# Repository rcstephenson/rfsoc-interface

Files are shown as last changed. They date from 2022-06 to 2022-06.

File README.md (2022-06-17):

# RFSoC Breakout Board

This repo is for KiCAD6 projects replacing the FMC-XM500 daughter card with a smaller version using low frequency baluns and external differential clocking breakout board. 

## RFSoC_Frontend:
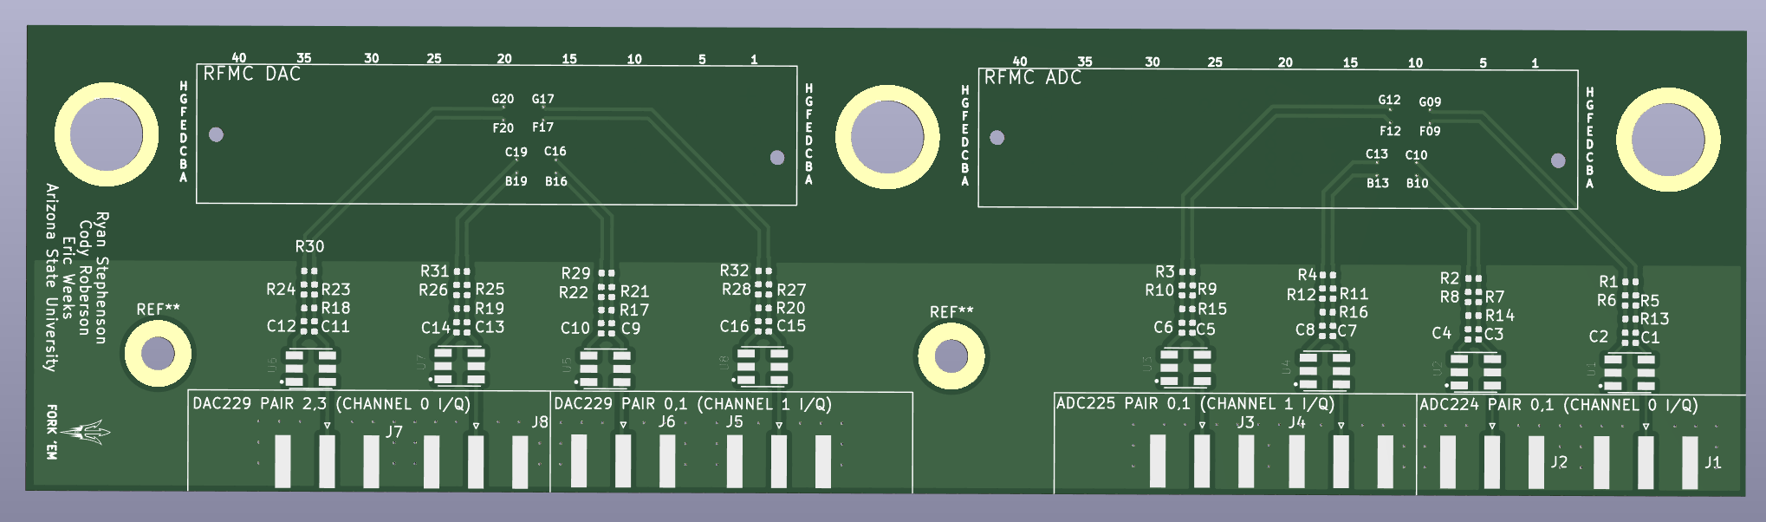
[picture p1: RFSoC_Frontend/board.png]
RFSoC front end breakout board


## RFSoC_directclocking:
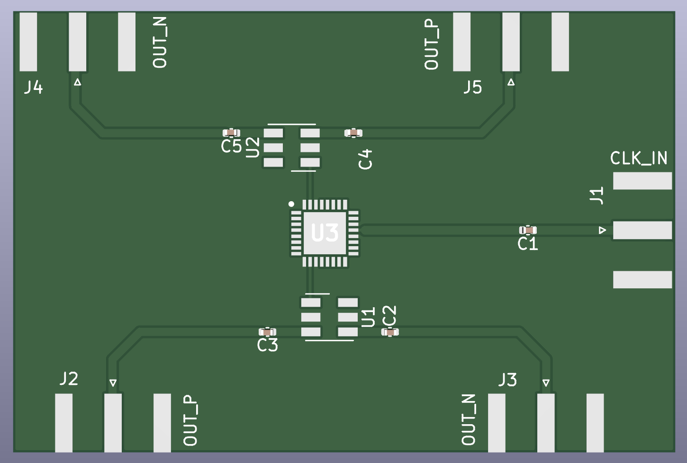
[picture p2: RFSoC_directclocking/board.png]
differential brekaout and power splitter for DAC/ADC


---
signifigent contributions have been made by Eric Weeks and Cody Roberson at ASU to make this board operational.

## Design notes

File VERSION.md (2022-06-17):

v0.1
- includes first three 2-channel boards fabricated, mounting holes were misaligned and did not physically fit on RFSoC. 
- Transmission lines are 50Ohm single ended grounded CPWs on input and 100Ohm differential microstrip lines before/after balun respectively. See XM500.pdf for original design info.

v1.0
- first fabricated version of board which works on RFSoC, same rf-lines, fixed position of mountion holes. 
- measuered I/Q data in loopback. 

added differential clocking board

V1.1
- added correct schematic to fix shorted grounds (Eric and Cody)
- updated PCB traces

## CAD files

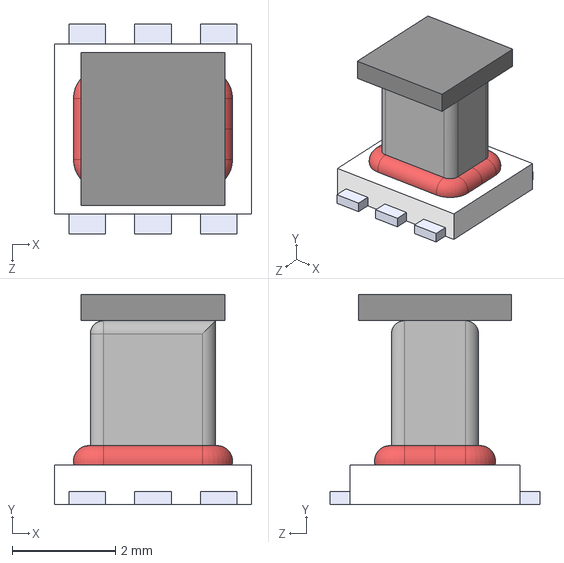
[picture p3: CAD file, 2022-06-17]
RFSoC_directclocking/TCM2-33WX_/TCM2-33WX_.step
3.81 x 4.06 x 4.06 mm

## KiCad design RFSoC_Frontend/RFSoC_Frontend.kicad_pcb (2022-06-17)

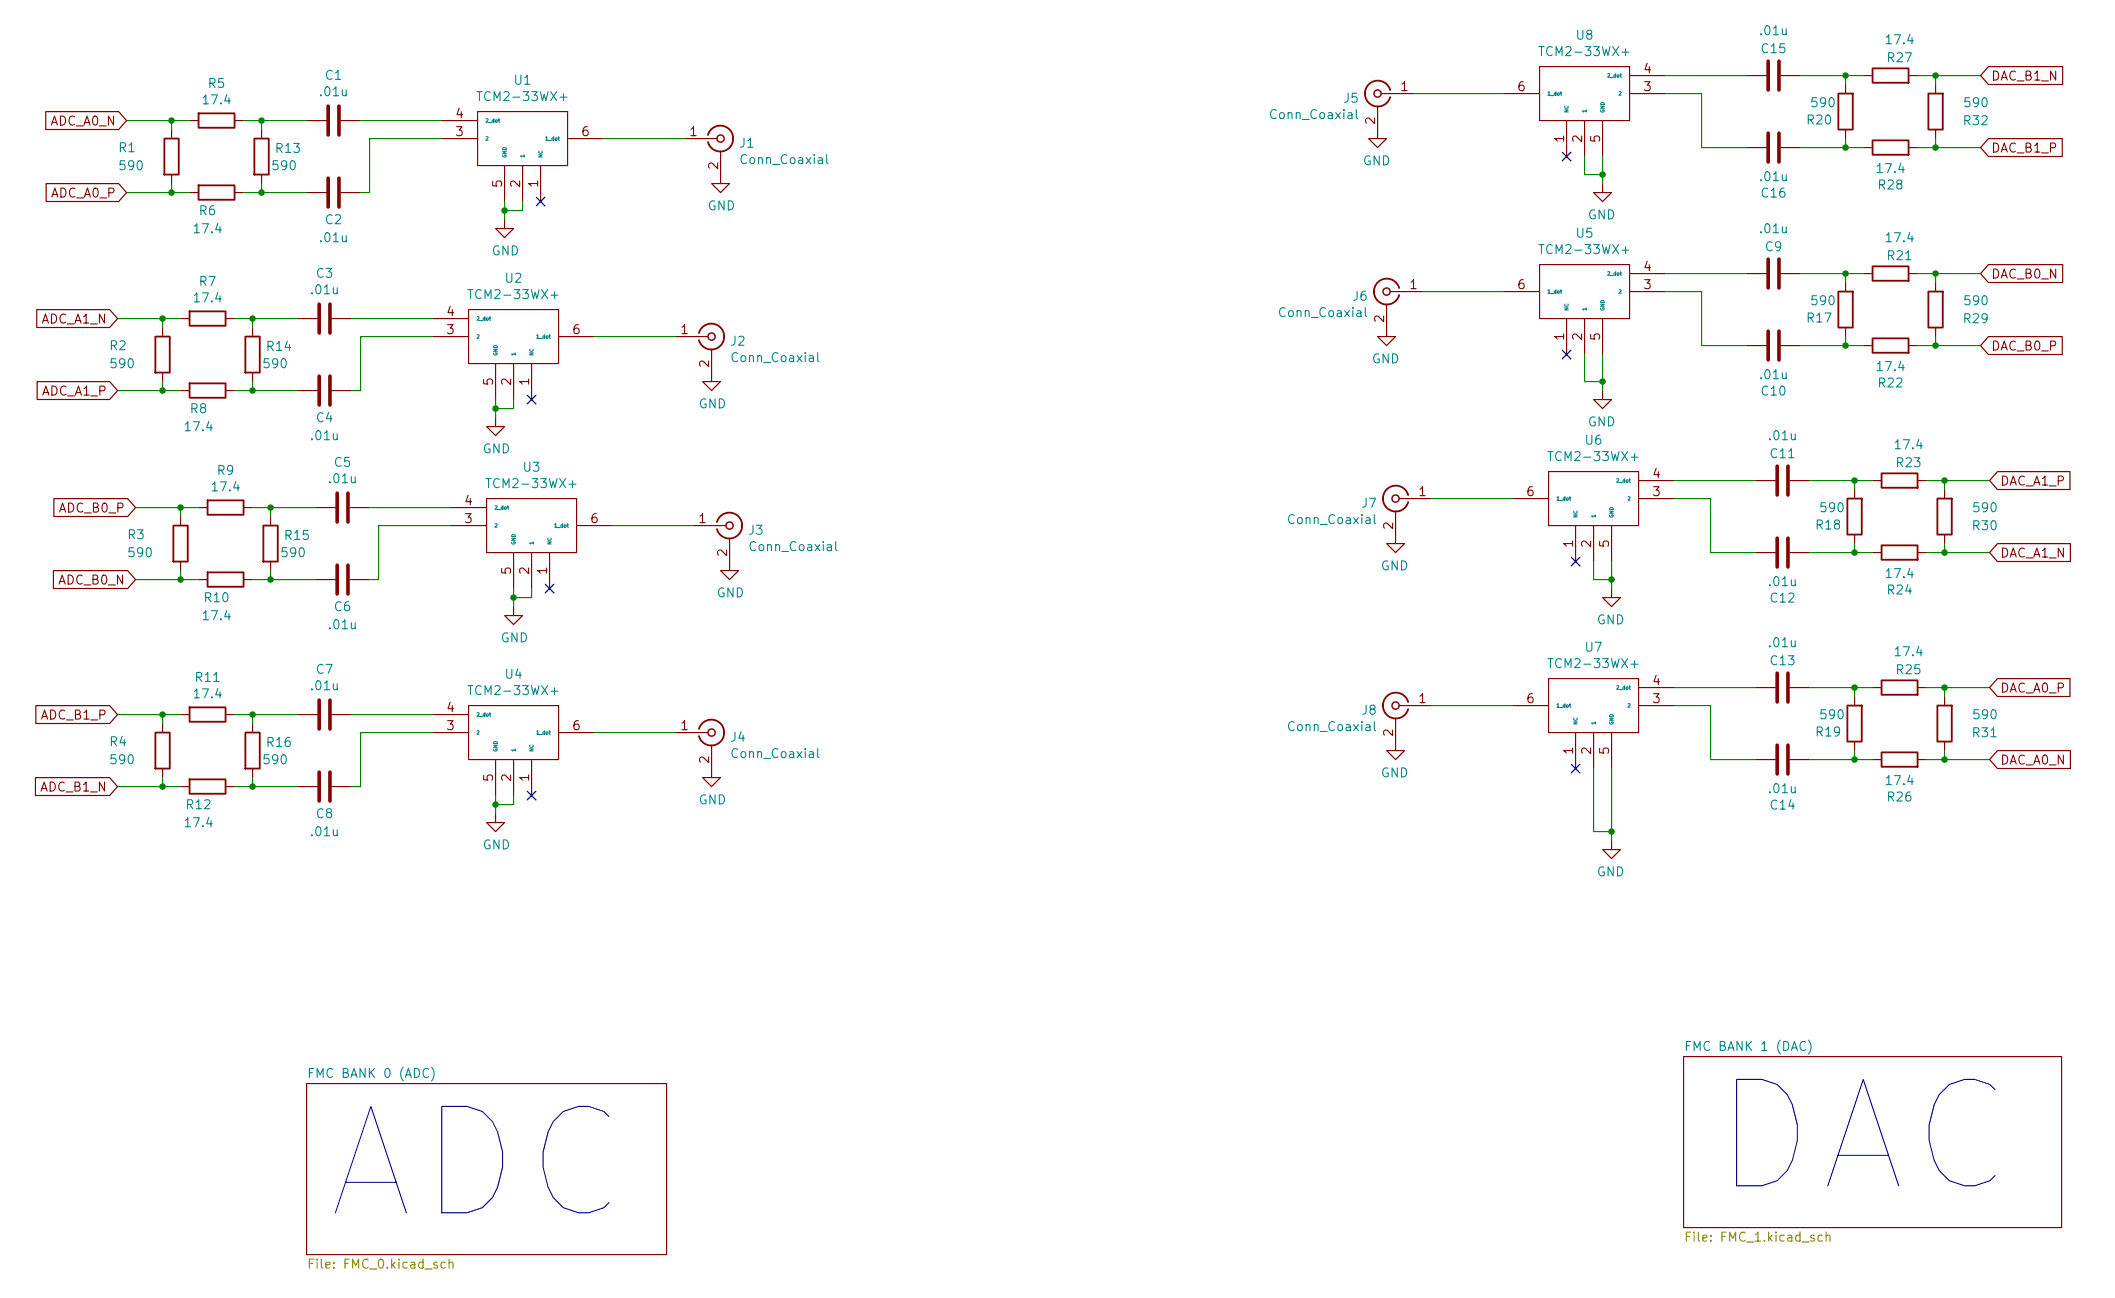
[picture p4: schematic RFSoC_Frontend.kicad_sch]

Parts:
C1, C2, C3, C4, C5, C6, C7, C8, C9, C10, C11, C12, C13, C14, C15, C16: .01u; C_0402_1005Metric
J1, J2, J3, J4, J5, J6, J7, J8: Conn_Coaxial; SMA_Amphenol_132289_EdgeMount
R1, R2, R3, R4, R13, R14, R15, R16, R17, R18, R19, R20, R29, R30, R31, R32: 590; R_0402_1005Metric
R5, R6, R7, R8, R9, R10, R11, R12, R21, R22, R23, R24, R25, R26, R27, R28: 17.4; R_0402_1005Metric
U1, U2, U3, U4, U5, U6, U7, U8: TCM2-33WX+; XFMR_TCM2-33WX+

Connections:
ADC_A0_N: R1.1, R5.2; also elsewhere on the board
ADC_A0_P: R1.2, R6.2; also elsewhere on the board
ADC_A1_N: R2.1, R7.2; also elsewhere on the board
ADC_A1_P: R2.2, R8.2; also elsewhere on the board
ADC_B0_N: R3.2, R10.2; also elsewhere on the board
ADC_B0_P: R3.1, R9.2; also elsewhere on the board
ADC_B1_N: R4.2, R12.2; also elsewhere on the board
ADC_B1_P: R4.1, R11.2; also elsewhere on the board
DAC_A0_N: R26.2, R31.1; also elsewhere on the board
DAC_A0_P: R25.2, R31.2; also elsewhere on the board
DAC_A1_N: R24.2, R30.1; also elsewhere on the board
DAC_A1_P: R23.2, R30.2; also elsewhere on the board
DAC_B0_N: R21.2, R29.2; also elsewhere on the board
DAC_B0_P: R22.2, R29.1; also elsewhere on the board
DAC_B1_N: R27.2, R32.2; also elsewhere on the board
DAC_B1_P: R28.2, R32.1; also elsewhere on the board
GND: J1.2 (Ext), J2.2 (Ext), J3.2 (Ext), J4.2 (Ext), J5.2 (Ext), J6.2 (Ext), J7.2 (Ext), J8.2 (Ext), U1.2 (1), U1.5 (GND), U2.2 (1), U2.5 (GND), U3.2 (1), U3.5 (GND), U4.2 (1), U4.5 (GND), U5.2 (1), U5.5 (GND), U6.2 (1), U6.5 (GND), U7.2 (1), U7.5 (GND), U8.2 (1), U8.5 (GND); also elsewhere on the board
unnamed: C1.1, U1.4 (2_dot)
unnamed: C1.2, R5.1, R13.1
unnamed: C2.1, U1.3 (2)
unnamed: C2.2, R6.1, R13.2
unnamed: C3.1, U2.4 (2_dot)
unnamed: C3.2, R7.1, R14.1
unnamed: C4.1, U2.3 (2)
unnamed: C4.2, R8.1, R14.2
unnamed: C5.1, U3.4 (2_dot)
unnamed: C5.2, R9.1, R15.1
unnamed: C6.1, U3.3 (2)
unnamed: C6.2, R10.1, R15.2
unnamed: C7.1, U4.4 (2_dot)
unnamed: C7.2, R11.1, R16.1
unnamed: C8.1, U4.3 (2)
unnamed: C8.2, R12.1, R16.2
unnamed: C9.1, U5.4 (2_dot)
unnamed: C9.2, R17.2, R21.1
unnamed: C10.1, U5.3 (2)
unnamed: C10.2, R17.1, R22.1
unnamed: C11.1, U6.4 (2_dot)
unnamed: C11.2, R18.2, R23.1
unnamed: C12.1, U6.3 (2)
unnamed: C12.2, R18.1, R24.1
unnamed: C13.1, U7.4 (2_dot)
unnamed: C13.2, R19.2, R25.1
unnamed: C14.1, U7.3 (2)
unnamed: C14.2, R19.1, R26.1
unnamed: C15.1, U8.4 (2_dot)
unnamed: C15.2, R20.2, R27.1
unnamed: C16.1, U8.3 (2)
unnamed: C16.2, R20.1, R28.1
unnamed: J1.1 (In), U1.6 (1_dot)
unnamed: J2.1 (In), U2.6 (1_dot)
unnamed: J3.1 (In), U3.6 (1_dot)
unnamed: J4.1 (In), U4.6 (1_dot)
unnamed: J5.1 (In), U8.6 (1_dot)
unnamed: J6.1 (In), U5.6 (1_dot)
unnamed: J7.1 (In), U6.6 (1_dot)
unnamed: J8.1 (In), U7.6 (1_dot)

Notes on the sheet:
ADC
DAC

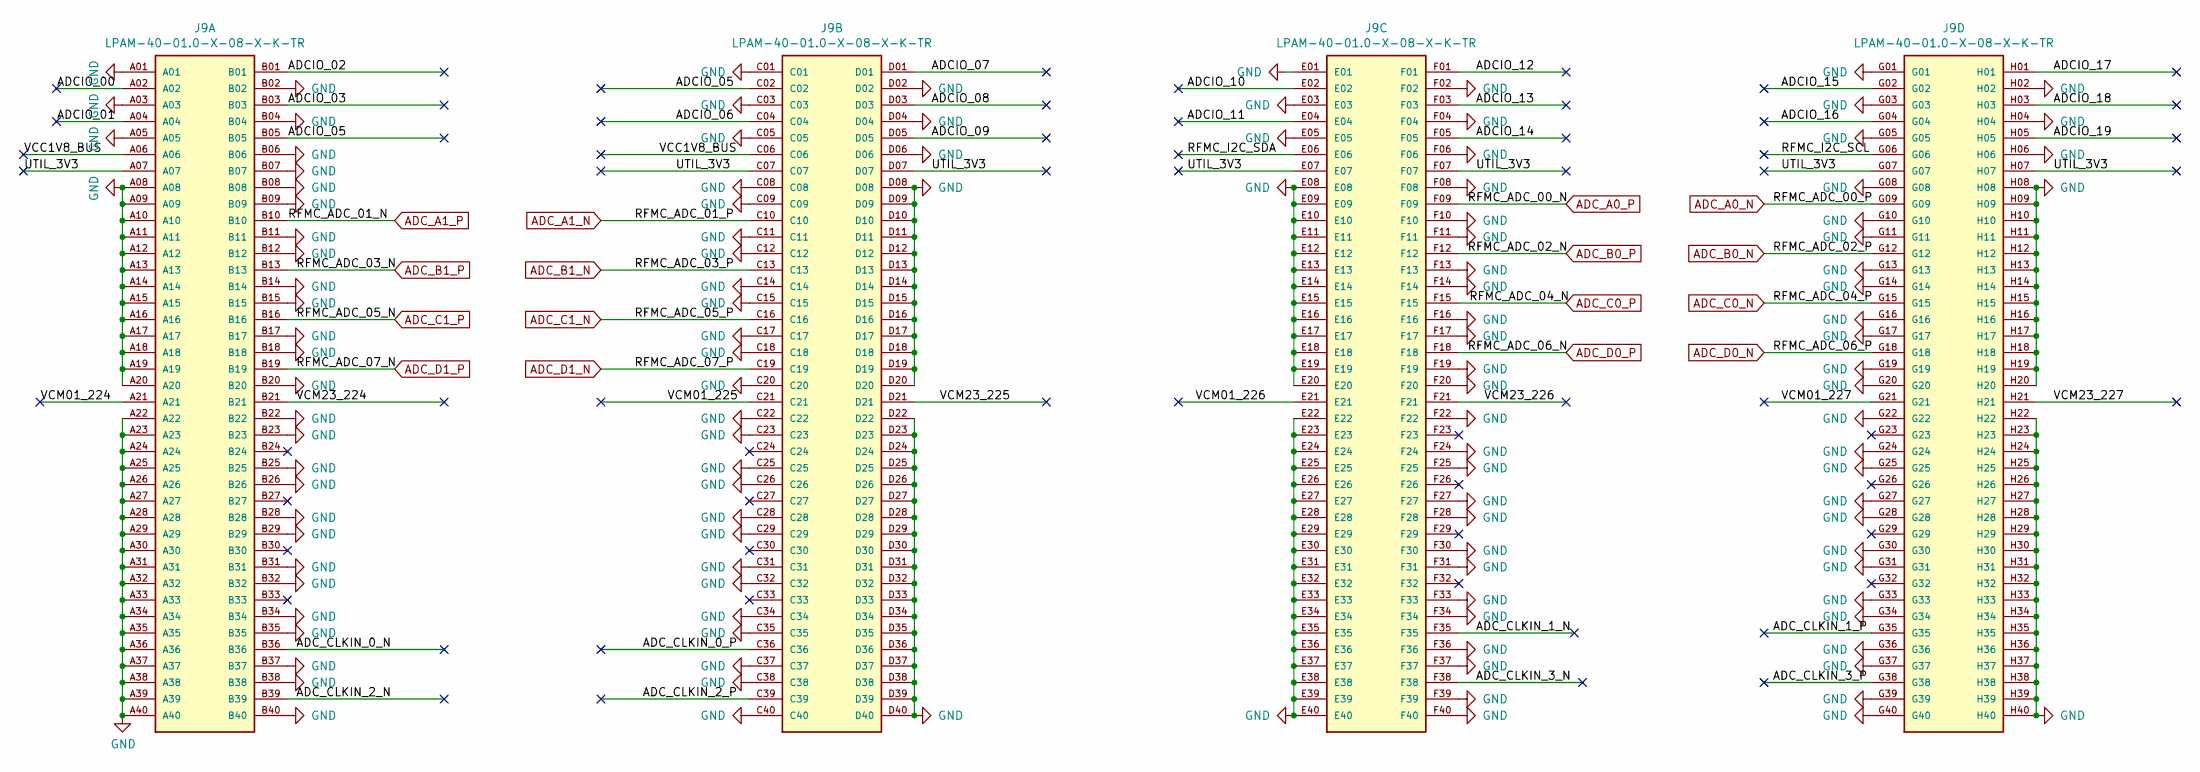
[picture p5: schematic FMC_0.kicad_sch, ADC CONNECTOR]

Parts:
J9: LPAM-40-01.0-X-08-X-K-TR; SAMTEC_LPAM-40-01.0-X-08-X-K-TR; PARTREV E

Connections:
/FMC BANK 0 (ADC)/ADCIO_00: J9.A02
/FMC BANK 0 (ADC)/ADCIO_01: J9.A04
/FMC BANK 0 (ADC)/ADCIO_02: J9.B01
/FMC BANK 0 (ADC)/ADCIO_03: J9.B03
/FMC BANK 0 (ADC)/ADCIO_05: J9.B05, J9.C02
/FMC BANK 0 (ADC)/ADCIO_06: J9.C04
/FMC BANK 0 (ADC)/ADCIO_07: J9.D01
/FMC BANK 0 (ADC)/ADCIO_08: J9.D03
/FMC BANK 0 (ADC)/ADCIO_09: J9.D05
/FMC BANK 0 (ADC)/ADCIO_10: J9.E02
/FMC BANK 0 (ADC)/ADCIO_11: J9.E04
/FMC BANK 0 (ADC)/ADCIO_12: J9.F01
/FMC BANK 0 (ADC)/ADCIO_13: J9.F03
/FMC BANK 0 (ADC)/ADCIO_14: J9.F05
/FMC BANK 0 (ADC)/ADCIO_15: J9.G02
/FMC BANK 0 (ADC)/ADCIO_16: J9.G04
/FMC BANK 0 (ADC)/ADCIO_17: J9.H01
/FMC BANK 0 (ADC)/ADCIO_18: J9.H03
/FMC BANK 0 (ADC)/ADCIO_19: J9.H05
/FMC BANK 0 (ADC)/ADC_CLKIN_0_N: J9.B36
/FMC BANK 0 (ADC)/ADC_CLKIN_0_P: J9.C36
/FMC BANK 0 (ADC)/ADC_CLKIN_1_N: J9.F35
/FMC BANK 0 (ADC)/ADC_CLKIN_1_P: J9.G35
/FMC BANK 0 (ADC)/ADC_CLKIN_2_N: J9.B39
/FMC BANK 0 (ADC)/ADC_CLKIN_2_P: J9.C39
/FMC BANK 0 (ADC)/ADC_CLKIN_3_N: J9.F38
/FMC BANK 0 (ADC)/ADC_CLKIN_3_P: J9.G38
/FMC BANK 0 (ADC)/RFMC_I2C_SCL: J9.G06
/FMC BANK 0 (ADC)/RFMC_I2C_SDA: J9.E06
/FMC BANK 0 (ADC)/UTIL_3V3: J9.A07, J9.C07, J9.D07, J9.E07, J9.F07, J9.G07, J9.H07
/FMC BANK 0 (ADC)/VCC1V8_BUS: J9.A06, J9.C06
/FMC BANK 0 (ADC)/VCM01_224: J9.A21
/FMC BANK 0 (ADC)/VCM01_225: J9.C21
/FMC BANK 0 (ADC)/VCM01_226: J9.E21
/FMC BANK 0 (ADC)/VCM01_227: J9.G21
/FMC BANK 0 (ADC)/VCM23_224: J9.B21
/FMC BANK 0 (ADC)/VCM23_225: J9.D21
/FMC BANK 0 (ADC)/VCM23_226: J9.F21
/FMC BANK 0 (ADC)/VCM23_227: J9.H21
ADC_A0_N: J9.G09; also elsewhere on the board
ADC_A0_P: J9.F09; also elsewhere on the board
ADC_A1_N: J9.C10; also elsewhere on the board
ADC_A1_P: J9.B10; also elsewhere on the board
ADC_B0_N: J9.G12; also elsewhere on the board
ADC_B0_P: J9.F12; also elsewhere on the board
ADC_B1_N: J9.C13; also elsewhere on the board
ADC_B1_P: J9.B13; also elsewhere on the board
ADC_C0_N: J9.G15
ADC_C0_P: J9.F15
ADC_C1_N: J9.C16
ADC_C1_P: J9.B16
ADC_D0_N: J9.G18
ADC_D0_P: J9.F18
ADC_D1_N: J9.C19
ADC_D1_P: J9.B19
GND: J9.A01, J9.A03, J9.A05, J9.A08, J9.A09, J9.A10, J9.A11, J9.A12, J9.A13, J9.A14, J9.A15, J9.A16, J9.A17, J9.A18, J9.A19, J9.A20, J9.A22, J9.A23, J9.A24, J9.A25, J9.A26, J9.A27, J9.A28, J9.A29, J9.A30, J9.A31, J9.A32, J9.A33, J9.A34, J9.A35, J9.A36, J9.A37, J9.A38, J9.A39, J9.A40, J9.B02, J9.B04, J9.B06, J9.B07, J9.B08, J9.B09, J9.B11, J9.B12, J9.B14, J9.B15, J9.B17, J9.B18, J9.B20, J9.B22, J9.B23, J9.B25, J9.B26, J9.B28, J9.B29, J9.B31, J9.B32, J9.B34, J9.B35, J9.B37, J9.B38, J9.B40, J9.C01, J9.C03, J9.C05, J9.C08, J9.C09, J9.C11, J9.C12, J9.C14, J9.C15, J9.C17, J9.C18, J9.C20, J9.C22, J9.C23, J9.C25, J9.C26, J9.C28, J9.C29, J9.C31, J9.C32, J9.C34, J9.C35, J9.C37, J9.C38, J9.C40, J9.D02, J9.D04, J9.D06, J9.D08, J9.D09, J9.D10, J9.D11, J9.D12, J9.D13, J9.D14, J9.D15, J9.D16, J9.D17, J9.D18, J9.D19, J9.D20, J9.D22, J9.D23, J9.D24, J9.D25, J9.D26, J9.D27, J9.D28, J9.D29, J9.D30, J9.D31, J9.D32, J9.D33, J9.D34, J9.D35, J9.D36, J9.D37, J9.D38, J9.D39, J9.D40, J9.E01, J9.E03, J9.E05, J9.E08, J9.E09, J9.E10, J9.E11, J9.E12, J9.E13, J9.E14, J9.E15, J9.E16, J9.E17, J9.E18, J9.E19, J9.E20, J9.E22, J9.E23, J9.E24, J9.E25, J9.E26, J9.E27, J9.E28, J9.E29, J9.E30, J9.E31, J9.E32, J9.E33, J9.E34, J9.E35, J9.E36, J9.E37, J9.E38, J9.E39, J9.E40, J9.F02, J9.F04, J9.F06, J9.F08, J9.F10, J9.F11, J9.F13, J9.F14, J9.F16, J9.F17, J9.F19, J9.F20, J9.F22, J9.F24, J9.F25, J9.F27, J9.F28, J9.F30, J9.F31, J9.F33, J9.F34, J9.F36, J9.F37, J9.F39, J9.F40, J9.G01, J9.G03, J9.G05, J9.G08, J9.G10, J9.G11, J9.G13, J9.G14, J9.G16, J9.G17, J9.G19, J9.G20, J9.G22, J9.G24, J9.G25, J9.G27, J9.G28, J9.G30, J9.G31, J9.G33, J9.G34, J9.G36, J9.G37, J9.G39, J9.G40, J9.H02, J9.H04, J9.H06, J9.H08, J9.H09, J9.H10, J9.H11, J9.H12, J9.H13, J9.H14, J9.H15, J9.H16, J9.H17, J9.H18, J9.H19, J9.H20, J9.H22, J9.H23, J9.H24, J9.H25, J9.H26, J9.H27, J9.H28, J9.H29, J9.H30, J9.H31, J9.H32, J9.H33, J9.H34, J9.H35, J9.H36, J9.H37, J9.H38, J9.H39, J9.H40; also elsewhere on the board

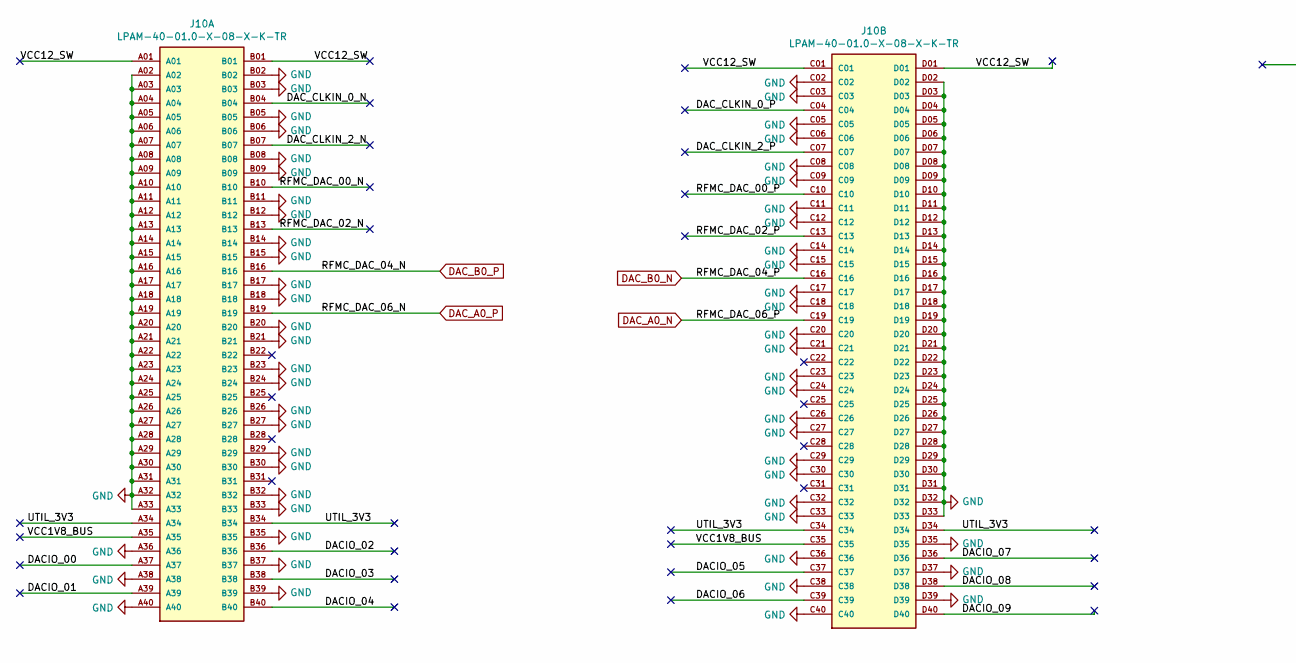
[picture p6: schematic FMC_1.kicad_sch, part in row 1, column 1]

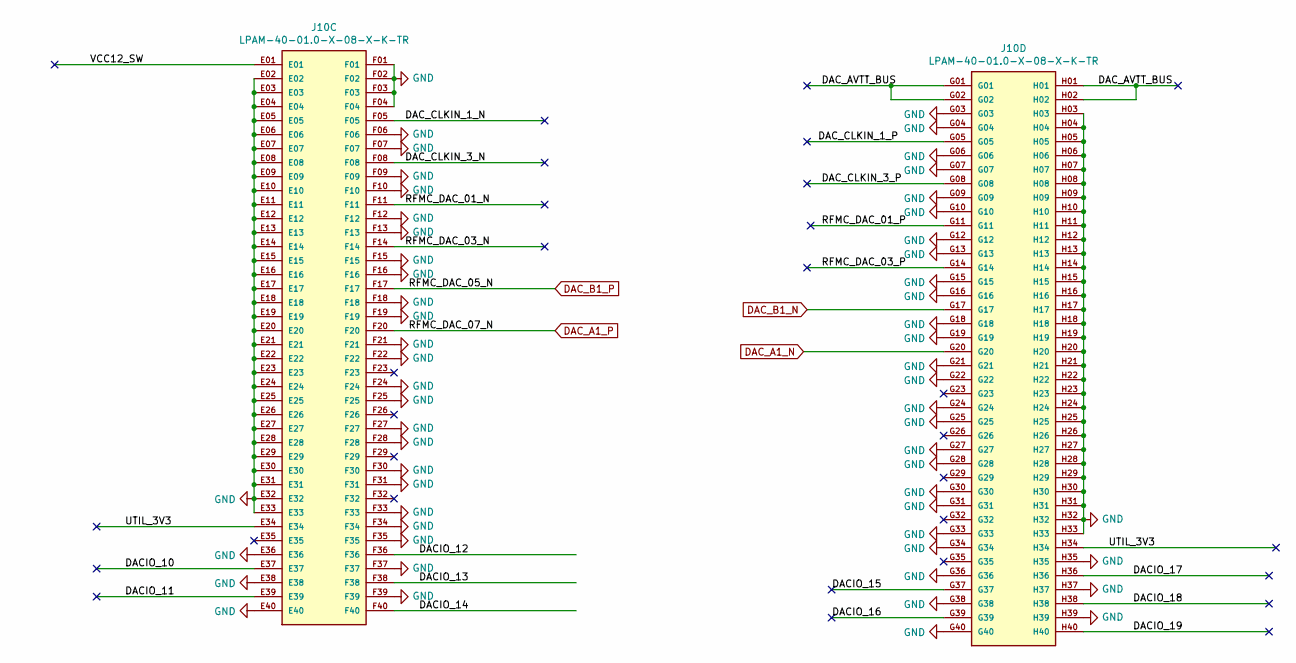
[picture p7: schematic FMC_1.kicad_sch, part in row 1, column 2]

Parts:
J10: LPAM-40-01.0-X-08-X-K-TR; SAMTEC_LPAM-40-01.0-X-08-X-K-TR; PARTREV E

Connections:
/FMC BANK 1 (DAC)/DACIO_00: J10.A37
/FMC BANK 1 (DAC)/DACIO_01: J10.A39
/FMC BANK 1 (DAC)/DACIO_02: J10.B36
/FMC BANK 1 (DAC)/DACIO_03: J10.B38
/FMC BANK 1 (DAC)/DACIO_04: J10.B40
/FMC BANK 1 (DAC)/DACIO_05: J10.C37
/FMC BANK 1 (DAC)/DACIO_06: J10.C39
/FMC BANK 1 (DAC)/DACIO_07: J10.D36
/FMC BANK 1 (DAC)/DACIO_08: J10.D38
/FMC BANK 1 (DAC)/DACIO_09: J10.D40
/FMC BANK 1 (DAC)/DACIO_10: J10.E37
/FMC BANK 1 (DAC)/DACIO_11: J10.E39
/FMC BANK 1 (DAC)/DACIO_12: J10.F36
/FMC BANK 1 (DAC)/DACIO_13: J10.F38
/FMC BANK 1 (DAC)/DACIO_14: J10.F40
/FMC BANK 1 (DAC)/DACIO_15: J10.G37
/FMC BANK 1 (DAC)/DACIO_16: J10.G39
/FMC BANK 1 (DAC)/DACIO_17: J10.H36
/FMC BANK 1 (DAC)/DACIO_18: J10.H38
/FMC BANK 1 (DAC)/DACIO_19: J10.H40
/FMC BANK 1 (DAC)/DAC_AVTT_BUS: J10.G01, J10.G02, J10.H01, J10.H02
/FMC BANK 1 (DAC)/DAC_CLKIN_0_N: J10.B04
/FMC BANK 1 (DAC)/DAC_CLKIN_0_P: J10.C04
/FMC BANK 1 (DAC)/DAC_CLKIN_1_N: J10.F05
/FMC BANK 1 (DAC)/DAC_CLKIN_1_P: J10.G05
/FMC BANK 1 (DAC)/DAC_CLKIN_2_N: J10.B07
/FMC BANK 1 (DAC)/DAC_CLKIN_2_P: J10.C07
/FMC BANK 1 (DAC)/DAC_CLKIN_3_N: J10.F08
/FMC BANK 1 (DAC)/DAC_CLKIN_3_P: J10.G08
/FMC BANK 1 (DAC)/RFMC_DAC_00_N: J10.B10
/FMC BANK 1 (DAC)/RFMC_DAC_00_P: J10.C10
/FMC BANK 1 (DAC)/RFMC_DAC_01_N: J10.F11
/FMC BANK 1 (DAC)/RFMC_DAC_01_P: J10.G11
/FMC BANK 1 (DAC)/RFMC_DAC_02_N: J10.B13
/FMC BANK 1 (DAC)/RFMC_DAC_02_P: J10.C13
/FMC BANK 1 (DAC)/RFMC_DAC_03_N: J10.F14
/FMC BANK 1 (DAC)/RFMC_DAC_03_P: J10.G14
/FMC BANK 1 (DAC)/UTIL_3V3: J10.A34, J10.B34, J10.C34, J10.D34, J10.E34, J10.H34
/FMC BANK 1 (DAC)/VCC1V8_BUS: J10.A35, J10.C35
/FMC BANK 1 (DAC)/VCC12_SW: J10.A01, J10.B01, J10.C01, J10.D01, J10.E01
DAC_A0_N: J10.C19; also elsewhere on the board
DAC_A0_P: J10.B19; also elsewhere on the board
DAC_A1_N: J10.G20; also elsewhere on the board
DAC_A1_P: J10.F20; also elsewhere on the board
DAC_B0_N: J10.C16; also elsewhere on the board
DAC_B0_P: J10.B16; also elsewhere on the board
DAC_B1_N: J10.G17; also elsewhere on the board
DAC_B1_P: J10.F17; also elsewhere on the board
GND: J10.A02, J10.A03, J10.A04, J10.A05, J10.A06, J10.A07, J10.A08, J10.A09, J10.A10, J10.A11, J10.A12, J10.A13, J10.A14, J10.A15, J10.A16, J10.A17, J10.A18, J10.A19, J10.A20, J10.A21, J10.A22, J10.A23, J10.A24, J10.A25, J10.A26, J10.A27, J10.A28, J10.A29, J10.A30, J10.A31, J10.A32, J10.A33, J10.A36, J10.A38, J10.A40, J10.B02, J10.B03, J10.B05, J10.B06, J10.B08, J10.B09, J10.B11, J10.B12, J10.B14, J10.B15, J10.B17, J10.B18, J10.B20, J10.B21, J10.B23, J10.B24, J10.B26, J10.B27, J10.B29, J10.B30, J10.B32, J10.B33, J10.B35, J10.B37, J10.B39, J10.C02, J10.C03, J10.C05, J10.C06, J10.C08, J10.C09, J10.C11, J10.C12, J10.C14, J10.C15, J10.C17, J10.C18, J10.C20, J10.C21, J10.C23, J10.C24, J10.C26, J10.C27, J10.C29, J10.C30, J10.C32, J10.C33, J10.C36, J10.C38, J10.C40, J10.D02, J10.D03, J10.D04, J10.D05, J10.D06, J10.D07, J10.D08, J10.D09, J10.D10, J10.D11, J10.D12, J10.D13, J10.D14, J10.D15, J10.D16, J10.D17, J10.D18, J10.D19, J10.D20, J10.D21, J10.D22, J10.D23, J10.D24, J10.D25, J10.D26, J10.D27, J10.D28, J10.D29, J10.D30, J10.D31, J10.D32, J10.D33, J10.D35, J10.D37, J10.D39, J10.E02, J10.E03, J10.E04, J10.E05, J10.E06, J10.E07, J10.E08, J10.E09, J10.E10, J10.E11, J10.E12, J10.E13, J10.E14, J10.E15, J10.E16, J10.E17, J10.E18, J10.E19, J10.E20, J10.E21, J10.E22, J10.E23, J10.E24, J10.E25, J10.E26, J10.E27, J10.E28, J10.E29, J10.E30, J10.E31, J10.E32, J10.E33, J10.E36, J10.E38, J10.E40, J10.F01, J10.F02, J10.F03, J10.F04, J10.F06, J10.F07, J10.F09, J10.F10, J10.F12, J10.F13, J10.F15, J10.F16, J10.F18, J10.F19, J10.F21, J10.F22, J10.F24, J10.F25, J10.F27, J10.F28, J10.F30, J10.F31, J10.F33, J10.F34, J10.F35, J10.F37, J10.F39, J10.G03, J10.G04, J10.G06, J10.G07, J10.G09, J10.G10, J10.G12, J10.G13, J10.G15, J10.G16, J10.G18, J10.G19, J10.G21, J10.G22, J10.G24, J10.G25, J10.G27, J10.G28, J10.G30, J10.G31, J10.G33, J10.G34, J10.G36, J10.G38, J10.G40, J10.H03, J10.H04, J10.H05, J10.H06, J10.H07, J10.H08, J10.H09, J10.H10, J10.H11, J10.H12, J10.H13, J10.H14, J10.H15, J10.H16, J10.H17, J10.H18, J10.H19, J10.H20, J10.H21, J10.H22, J10.H23, J10.H24, J10.H25, J10.H26, J10.H27, J10.H28, J10.H29, J10.H30, J10.H31, J10.H32, J10.H33, J10.H35, J10.H37, J10.H39; also elsewhere on the board

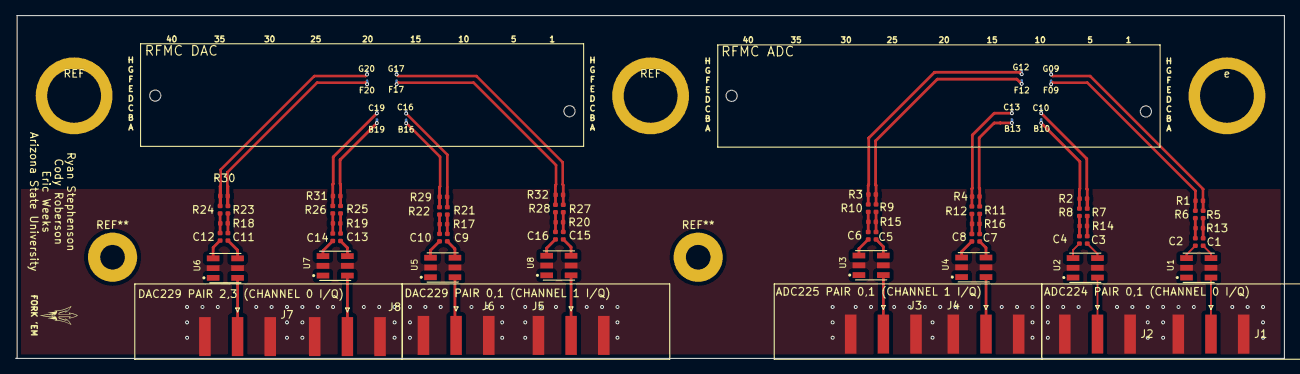
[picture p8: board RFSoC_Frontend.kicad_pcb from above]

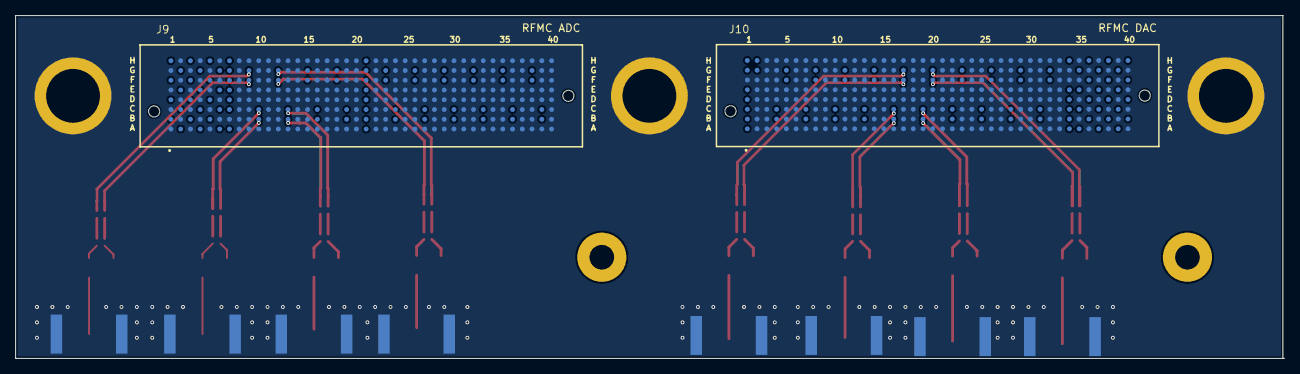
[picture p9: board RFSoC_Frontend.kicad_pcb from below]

Board: 4 copper layers, 165.1 x 44.6 mm, 69 parts (2 on the bottom side), 64 nets.

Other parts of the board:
REF: MountingHole_2.2mm_M2_DIN965_Pad
REF#2: MountingHole_2.2mm_M2_DIN965_Pad
e: MountingHole_2.2mm_M2_DIN965_Pad

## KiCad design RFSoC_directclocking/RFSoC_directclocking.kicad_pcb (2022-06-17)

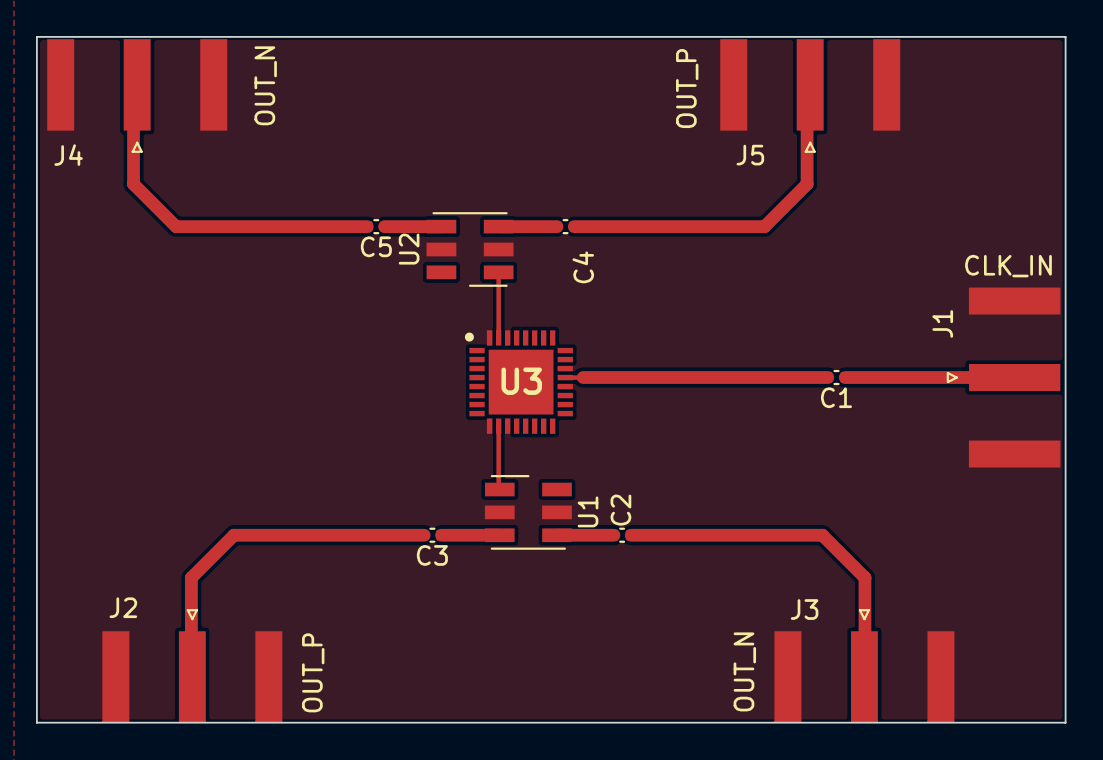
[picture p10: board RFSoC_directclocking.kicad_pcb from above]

Board: 2 copper layers, 57.2 x 38.1 mm, 13 parts (0 on the bottom side), 13 nets.

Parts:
C1: C; C_0402_1005Metric
C2, C3, C4, C5: .01u; C_0402_1005Metric
J1, J2, J3, J4, J5: Conn_Coaxial; SMA_Amphenol_132289_EdgeMount
U1, U2: Mini-Circuits_DB1627
U3: EP2RCW+; QFN50P500X500X100-33N-D

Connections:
GND: J1.2 (Ext), J2.2 (Ext), J3.2 (Ext), J4.2 (Ext), J5.2 (Ext), U1.2 (1), U1.5 (GND), U2.2 (1), U2.5 (GND), U3.9 (GND), U3.11 (GND), U3.20 (GND), U3.22 (GND), U3.30 (GND), U3.32 (GND)
unnamed: C1.1, J1.1 (In)
unnamed: C1.2, U3.21 (RF_IN)
unnamed: C2.1, U1.3 (2)
unnamed: C2.2, J3.1 (In)
unnamed: C3.1, U1.4 (2_dot)
unnamed: C3.2, J2.1 (In)
unnamed: C4.1, U2.4 (2_dot)
unnamed: C4.2, J5.1 (In)
unnamed: C5.1, U2.3 (2)
unnamed: C5.2, J4.1 (In)
unnamed: U1.6 (1_dot), U3.10 (RF_OUT_1)
unnamed: U2.6 (1_dot), U3.31 (RFOUT2)

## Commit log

2021-10-20 init commit
    [FMC_0.sch, FMC_1.sch, RFSoC_Frontend_v0.1.kicad_pcb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]
2021-10-26 resize board
    [RFSoC_Frontend_v0.1.kicad_pcb, RFSoC_Frontend_v0.1.sch]
2021-11-05 route differential lines
    [RFSoC_Frontend_v0.1.kicad_pcb]
2022-02-23 added v1.0 board for kicad6
    first working version of RFSoC interface board for 2 channels bellow 1GHz
    [FMC_0.kicad_sch, FMC_0.sch, FMC_1.kicad_sch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]
2022-03-07 add direct clocking board
    this design is to break out a single clock line into 2 differential lines to drive a DAC-ADC pair
    [RFSoC_Frontend.kicad_pcb, RFSoC_directclocking.kicad_pcb, RFSoC_directclocking.kicad_sch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]
2022-03-09 mc lib components
    [RFSoC_directclocking.kicad_pcb]
2022-03-14 pmod board update
    [RFSoC_directclocking.kicad_sch]
2022-06-09 Squashed commit of the following:
    commit 11c362fd04afcdda8fc54016fc262973d8ee90dd
    Author: cody <you@example.com>
    Date: Sat May 14 20:18:42 2022 -0700
    updated silkscreens, degin DRC corrections
    commit c03c76887280f84603892cf274eefb7fb13b0fa8
    Author: cody <you@example.com>
    Date: Fri May 13 16:10:57 2022 -0700
    fork em
    commit e1673cb11a9ebe940ceda00a5b2ec080c415b465
    Author: cody <you@example.com>
    Date: Fri May 13 15:38:00 2022 -0700
    updated all
    commit 84fbdba19d4f5d8a85804f2c5d387b833a8e7f5e
    Author: Cody Roberson <carobers@asu.edu>
    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
    [FMC_0.kicad_sch, FMC_1.kicad_sch, RFSoC_Frontend.kicad_pcb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]
2022-06-09 merging changes from @codyroberson
    Changes include Cody and Eric's modification of the rf breakout board, and direct rf clock board.
2022-06-17 deleted unused files
    [RFSoC_Frontend.kicad_pcb]
2022-06-17 added board.png and updated info
